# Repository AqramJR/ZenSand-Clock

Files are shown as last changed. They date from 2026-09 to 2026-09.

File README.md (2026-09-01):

# ⏳ ZenSand Clock: The Smart Kinetic Sand Art

A premium, 3D-printed Smart Kinetic Sand Art Clock powered by ESP32. This project combines the mesmerizing, continuous motion of a kinetic sand wiper with a feature-rich, 100% non-blocking software architecture. 

It serves not only as an aesthetically pleasing desk clock but also as a fully functional Smart Home IoT device featuring a local Web Dashboard, live weather synchronization, Pomodoro focus mode, and smooth embedded animations.

## ✨ Key Features

* **100% Non-Blocking Architecture:** Built entirely on `millis()` state machines. The 28BYJ-48 stepper motor runs flawlessly using `AccelStepper::runSpeed()` without a single `delay()`, ensuring the sand wiper never stutters, even during Wi-Fi connection or HTTP parsing.
* **Local Web Dashboard:** A built-in, mobile-friendly HTML/JS web server. Adjust motor RPM, toggle direction, change clock faces, tweak OLED brightness, or send scrolling messages to the screen instantly from your phone.
* **Live Weather & NTP Sync:** Connects to Wi-Fi on-demand (or keeps it alive) to sync exact time via NTP and fetches live weather data (temperature & conditions) from the Open-Meteo API (No API key required!).
* **Pomodoro Zen Mode:** A dedicated focus timer (25m work / 5m break). The sand moves agonizingly slow while you focus, then speeds up to "wipe the slate clean" during your break.
* **Smart Auto-Wipe:** Configurable daily schedules (e.g., 03:00 and 15:00) where the motor ramps up to maximum RPM for a deep sand-cleaning cycle.
* **Easter Egg Mini-Game:** Tap the capacitive sensor exactly 5 times rapidly to launch a hidden "Dino Jump" side-scroller game on the OLED!
* **Advanced U8g2 Animations:** Features multiple parallax and mathematically driven clock faces (e.g., Cyberpunk Neon Skyline, Star Voyage) running purely on calculated geometry.

## 🛠️ Hardware Requirements

* **Microcontroller:** ESP32 (NodeMCU-32S / WROOM-32)
* **Display:** 1.3" OLED SH1106 (I2C)
* **Touch Sensor:** TTP223 Capacitive Touch Module
* **Motor & Driver:** 28BYJ-48 Stepper Motor + ULN2003 Driver Board
* **RTC Module:** DS1307 (I2C) + CR2032 Coin Cell Battery
* **Sand Medium:** Kinetic sand (or ultra-fine baking soda)
* **Chassis:** 3D Printed housing (Sand tray and motor mount).

## 💻 Software Dependencies

Ensure you have the following libraries installed in your Arduino IDE:
* `U8g2` by olikraus
* `AccelStepper` by Mike McCauley
* `RTClib` by Adafruit
* `ArduinoJson` by Benoit Blanchon (v6.x)
* Built-in ESP32 Libraries: `WiFi.h`, `Preferences.h`, `WebServer.h`, `HTTPClient.h`

## 🔌 Wiring Guide

| Component | Pin | ESP32 Pin |
| :--- | :--- | :--- |
| **OLED & RTC** | SDA | `GPIO 21` |
| **OLED & RTC** | SCL | `GPIO 22` |
| **TTP223 Touch** | SIG | `GPIO 4` |
| **ULN2003 IN1** | IN1 | `GPIO 13` |
| **ULN2003 IN2** | IN2 | `GPIO 14` |
| **ULN2003 IN3** | IN3 | `GPIO 12` |
| **ULN2003 IN4** | IN4 | `GPIO 27` |

*(Note: The `AccelStepper` constructor in the code correctly handles the IN1-IN3-IN2-IN4 half-step sequence required for the 28BYJ-48 motor).*

## ⚙️ Software Setup

1. Install the latest **Arduino IDE**.
2. Add the ESP32 board package to your Boards Manager.
3. Install the following libraries via the Library Manager:
   * `U8g2` by olikraus
   * `AccelStepper` by Mike McCauley
   * `RTClib` by Adafruit
   * `ArduinoJson` by Benoit Blanchon
4. Open the `.ino` file and update your Wi-Fi credentials:
   ```cpp
   const char* WIFI_SSID     = "YOUR_SSID";
   const char* WIFI_PASSWORD = "YOUR_PASSWORD";
   ```
5. Adjust your Timezone offsets if necessary:
   ```cpp
   const long  GMT_OFFSET_SEC   = 7200;   // Example: UTC+2 (Egypt)
   const int   DST_OFFSET_SEC   = 0;      // Example: Daylight Savings Time
   ```
6. Compile and upload to your ESP32.

---

## 🚀 What's Next? (Future Upgrades)

This project is continuously evolving. Here is the roadmap for upcoming enhancements:

### 🔩 Hardware Upgrades
* **Battery Independence:** Integrate an 18650 Li-ion battery, TP4056 charging module, and MT3608 boost converter for a truly wire-free centerpiece.
* **Neopixel Edge-Lighting:** Add an addressable WS2812B LED strip beneath the sand basin. The ESP32 can sync the sand color with the current weather, time of day, or Pomodoro status.
* **Acoustic Ambience:** Incorporate a DFPlayer Mini and a 3W speaker to play Zen/Lo-Fi music, rain sounds, or an elegant hourly chime.
* **Glass Dome Enclosure:** Fit a custom acrylic or tempered glass dome to protect the sand from dust and humidity.

### 💾 Software/Firmware Upgrades
* **OTA (Over-The-Air) Updates:** Flash new firmware wirelessly through the web dashboard without dismantling the clock.
* **Kinetic Spirograph Patterns:** Upgrade the motor control math to draw complex geometric Mandala and Lissajous curves instead of simple circles.
* **Moon Phase Clock Face:** Calculate and render accurate lunar phases on the OLED alongside the date and time.
* **Kinetic Alarm Clock:** An alarm mode that vibrates the stepper motor rapidly and flashes the OLED to wake you up without needing a buzzer.

## 📝 License
This project is open-source. Feel free to fork, modify, and build your own ZenSand Clock!

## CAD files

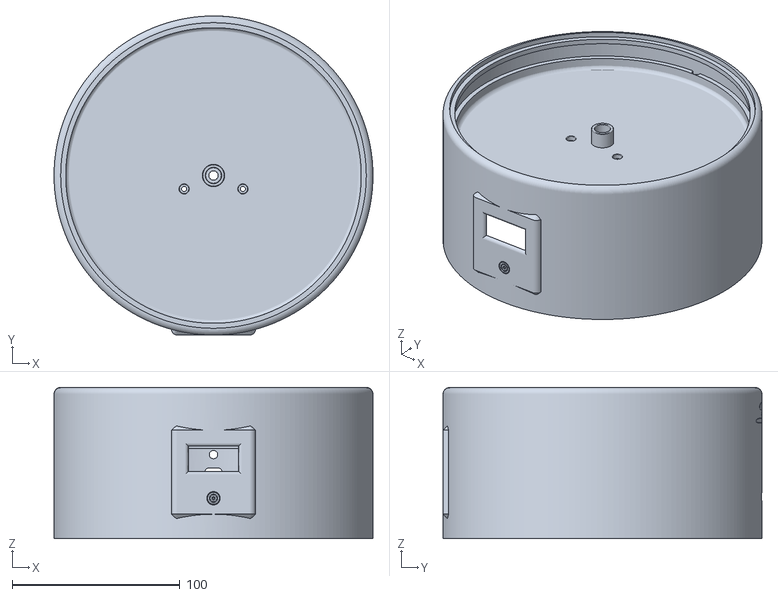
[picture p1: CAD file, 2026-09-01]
3D print/Main_Body_V2.stl
190.0 x 190.0 x 90.0

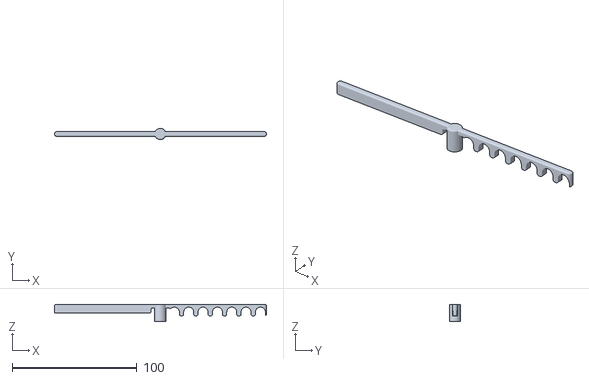
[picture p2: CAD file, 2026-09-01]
3D print/Sand_Wiper.stl
170.0 x 9.00 x 14.0

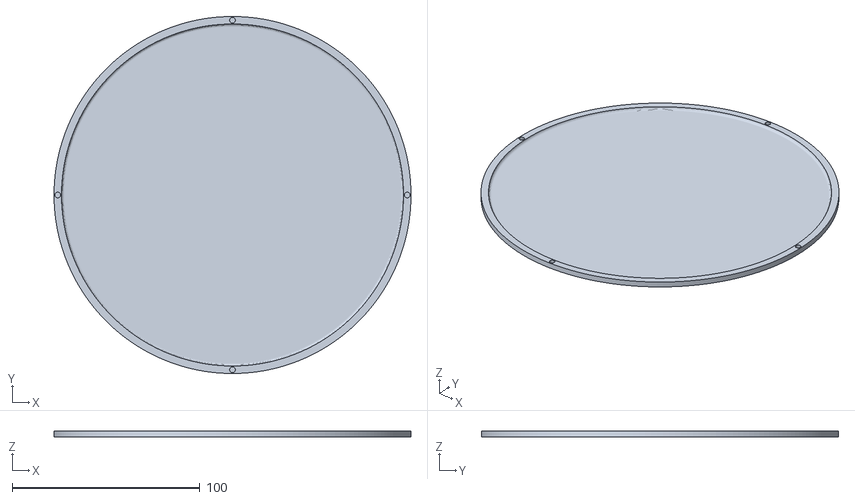
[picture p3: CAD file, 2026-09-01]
3D print/Bottom_Cover.stl
190.0 x 190.0 x 3.00

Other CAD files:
3D print/SmartSandClock.f3z

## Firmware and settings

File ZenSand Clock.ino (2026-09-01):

/*
 * ============================================================================
 *  SMART KINETIC SAND ART CLOCK — ESP32  (PREMIUM SMART-HOME EDITION)
 * ============================================================================
 *  Hardware:
 *    - ESP32 (NodeMCU-32S)
 *    - 1.3" OLED SH1106, I2C            -> U8g2 (full buffer, hardware I2C)
 *    - TTP223 capacitive touch          -> GPIO 4, Active HIGH
 *    - 28BYJ-48 + ULN2003               -> GPIO 13, 14, 12, 27, AccelStepper
 *    - DS1307 RTC, I2C                  -> RTClib (Adafruit)
 *
 *  Libraries required (Library Manager):
 *    - U8g2 by olikraus
 *    - AccelStepper by Mike McCauley
 *    - RTClib by Adafruit
 *    - ArduinoJson by Benoit Blanchon (v6.x)
 *    - (built into ESP32 core) Preferences.h, WiFi.h, time.h, WebServer.h,
 *      HTTPClient.h, Update.h
 *
 *  ============================================================================
 *  WHAT'S NEW IN THIS EDITION (6 features layered onto the original base)
 *  ============================================================================
 *   1. Local Web Dashboard   - WebServer.h, fully non-blocking (server.handleClient()
 *                              is called once per loop(), same as stepper.runSpeed()).
 *                              Mobile-friendly single-page HTML/CSS/JS control panel.
 *   2. Web Message Billboard - text box on the dashboard -> SystemState::BILLBOARD,
 *                              a millis()-driven horizontal scroll for ~5s.
 *   3. Live Weather Sync     - piggybacks on the existing WiFi/NTP state machine;
 *                              one extra (still non-blocking-to-the-motor) HTTPClient
 *                              call, parsed with ArduinoJson. New ClockFace::WEATHER.
 *   4. Pomodoro Zen Mode     - SystemState::POMODORO, 25-min work (RPM_MIN) / 5-min
 *                              break (RPM_MAX) cycle with a big countdown.
 *   5. Smart 12h Auto-Wipe   - fires automatically at 03:00 and 15:00 for a 2-minute
 *                              full-speed sweep, independent of the manual per-hour
 *                              auto-wipe setting already in Motor Settings.
 *   6. Easter-Egg Mini-Game  - 5 rapid taps inside the tap window launches a simple
 *                              non-blocking "Dino Jump" game; short tap = jump,
 *                              long-press or a loss exits back to the clock.
 *
 *  ============================================================================
 *  THIS REVISION ADDS
 *  ============================================================================
 *   7. OTA Firmware Update   - Update.h + a "/update" POST endpoint reachable
 *                              from the web dashboard. Standard synchronous
 *                              WebServer OTA pattern. NOTE: because WebServer
 *                              reads the whole multipart upload inside a single
 *                              server.handleClient() call, the stepper WILL
 *                              pause for the (short) duration of the upload +
 *                              flash write - this is an inherent limitation of
 *                              using the synchronous WebServer library for OTA,
 *                              not an oversight. yield() is called on every
 *                              received chunk so the watchdog never trips.
 *   8. Moon Phase Clock Face - ClockFace::MOON_PHASE. Phase is computed with a
 *                              lightweight Conway synodic-month approximation
 *                              (cheap integer/float math, no blocking calls,
 *                              no external library) and rendered as a real
 *                              illuminated disc using a per-scanline terminator
 *                              calculation (sqrt + cos, drawn with u8g2.drawHLine).
 *   9. WiFi Sync IP Display  - drawWifiSyncScreen() now prints WiFi.localIP()
 *                              on the OLED once sync succeeds, so the user can
 *                              find the dashboard without a Serial Monitor.
 *  10. "Always On" Label     - SLEEP_OPTIONS[0] (=0 minutes/never sleep) is now
 *                              rendered as "Always On" in both the OLED Display
 *                              Settings menu and the web dashboard status line.
 *
 *  ============================================================================
 *  THIS REVISION ALSO ADDS
 *  ============================================================================
 *  11. Zen Breathing Face    - ClockFace::ZEN_BREATHING. A sine-driven circle
 *                              that expands/contracts on an 8s inhale/exhale
 *                              cycle. Creative touch: updateZenBreathingMotor()
 *                              (called once per loop() pass, just like the
 *                              stepper itself) gently modulates motorRPM
 *                              +-30% around whatever speed the user had set,
 *                              faster at the inhale peak, slower on the
 *                              exhale - turning the wiper into a tactile
 *                              breathing pacer. The user's original RPM/dir/
 *                              run-state is saved on entry and restored
 *                              exactly on exit, so nothing else is disturbed.
 *  12. Generative Sand Art   - ClockFace::GENERATIVE_ART. A lightweight
 *                              falling-sand cellular automaton (64x32 logical
 *                              grid, 2px cells) that trickles grains downward
 *                              and piles them up, redrawn once per throttled
 *                              display refresh (same 200ms cadence as every
 *                              other face, so it never competes with the
 *                              stepper for CPU time). The digital time is
 *                              drawn on top inside a solid-filled panel so
 *                              it always stays crisp and readable.
 *  13. IP Wrap Fix           - drawWifiSyncScreen() now renders the synced
 *                              dashboard IP with a compact "IP: " prefix on
 *                              the small 5x7 font and centers/measures it
 *                              with getStrWidth() before drawing, so a full
 *                              IPv4 address ("IP: 255.255.255.255") always
 *                              fits inside the 128px screen width instead of
 *                              being clipped off the right edge.
 *
 *  Design notes (unchanged core philosophy):
 *    - ZERO calls to delay() anywhere in the steady-state loop() path. Every
 *      timed behaviour is driven off millis() state machines so the stepper
 *      and the touch polling are never blocked for more than a few
 *      milliseconds (the unavoidable I2C transfer time when we push a frame
 *      to the OLED). The ONE exception in the whole sketch is a short,
 *      clearly-commented delay() in handleUpdateResult(), used only after a
 *      successful OTA flash, immediately before ESP.restart() - at that point
 *      the MCU is about to fully reboot and re-initialise everything, so it
 *      has no bearing on the "smooth stepper during normal operation"
 *      guarantee.
 *    - AccelStepper::runSpeed() is called on every single pass through
 *      loop() so the sand wiper keeps perfectly smooth, constant-velocity
 *      motion regardless of what the UI/touch/web/HTTP logic is doing.
 *    - WebServer::handleClient() and the weather HTTPClient call are the two
 *      operations most likely to introduce latency; handleClient() is cheap
 *      and non-blocking by design, and the weather HTTP GET is only ever
 *      issued once per NTP sync (a rare, user-initiated or hourly event),
 *      immediately followed by stepper.runSpeed() calls before and after so
 *      any momentary stall is bounded and imperceptible on a slow sand wiper.
 *      The OTA upload endpoint is the sole exception, documented above.
 * ============================================================================
 */

#include <Arduino.h>
#include <Wire.h>
#include <U8g2lib.h>
#include <AccelStepper.h>
#include <RTClib.h>
#include <Preferences.h>   // NVS persistence
#include <WiFi.h>          // NTP sync + Web Dashboard + Weather
#include <time.h>          // configTime()/time()
#include <WebServer.h>     // Feature 1: local web dashboard
#include <HTTPClient.h>     // Feature 3: OpenWeatherMap / Open-Meteo
#include <ArduinoJson.h>    // Feature 3: JSON parsing
#include <Update.h>         // Feature 7: OTA firmware updates

// ============================================================================
//  PIN DEFINITIONS
// ============================================================================
static const uint8_t PIN_TOUCH   = 4;                 // TTP223, active HIGH

static const uint8_t PIN_STEP_IN1 = 13;
static const uint8_t PIN_STEP_IN2 = 14;
static const uint8_t PIN_STEP_IN3 = 12;
static const uint8_t PIN_STEP_IN4 = 27;

// ============================================================================
//  DISPLAY  (SH1106, full frame buffer, hardware I2C)
// ============================================================================
U8G2_SH1106_128X64_NONAME_F_HW_I2C u8g2(U8G2_R0, /* reset=*/ U8X8_PIN_NONE);

// ============================================================================
//  RTC
// ============================================================================
RTC_DS1307 rtc;
bool rtcAvailable = false;

// ============================================================================
//  STEPPER  (28BYJ-48 / ULN2003, half-step mode -> 2048 steps/rev)
// ============================================================================
AccelStepper stepper(AccelStepper::HALF4WIRE,
                      PIN_STEP_IN1, PIN_STEP_IN3, PIN_STEP_IN2, PIN_STEP_IN4);

static const float STEPS_PER_REV = 2048.0f;

float    motorRPM      = 1.0f;   // default: 1 RPM
int8_t   motorDirection = 1;     // +1 = clockwise, -1 = counter-clockwise
bool     motorRunning   = true;

static const float RPM_STEP = 5.0f;
static const float RPM_MIN  = 1.0f;
static const float RPM_MAX  = 15.0f;

// ============================================================================
//  PERSISTENT SETTINGS (NVS via Preferences)
// ============================================================================
Preferences prefs;
static const char* NVS_NAMESPACE = "sandclock";

// ============================================================================
//  STATE MACHINE & MENUS
// ============================================================================
enum class SystemState : uint8_t {
  BOOT, MAIN_SCREEN, SETTINGS_MENU, MOTOR_MENU, DISPLAY_MENU, TIME_SET_MENU,
  ANIMATION, WIFI_SYNC, WIPE_ACTIVE,
  POMODORO,     // Feature 4
  BILLBOARD,    // Feature 2
  GAME          // Feature 6
};

enum class ClockFace : uint8_t {
  DIGITAL_HUGE, ANALOG_CLOCK, DATE_TIME, BINARY_CLOCK, RPM_VIEW,
  CARTOON_MODE, CARTOON_MOVIE_2,
  WEATHER,        // Feature 3
  MOON_PHASE,     // Feature 8
  ZEN_BREATHING,  // Feature 11 (this revision)
  GENERATIVE_ART, // Feature 12 (this revision)
  FACE_COUNT
};

SystemState currentState  = SystemState::BOOT;
SystemState stateBeforeAnimation = SystemState::MAIN_SCREEN;
ClockFace   currentFace   = ClockFace::DIGITAL_HUGE;

uint8_t settingsMenuIndex = 0;
uint8_t motorMenuIndex    = 0;
uint8_t displayMenuIndex  = 0;
uint8_t timeSetStep = 0; // 0 = hours, 1 = minutes
int8_t tempHour = 0;
int8_t tempMinute = 0;

// Settings menu now offers Pomodoro entry too.
const char* SETTINGS_ITEMS[] = { "1.Motor Settings", "2.Display Settings", "3.Set Time", "4.Sync WiFi Time", "5.Pomodoro Mode", "< Back" };
const uint8_t SETTINGS_ITEM_COUNT = 6;
static const uint8_t SETTINGS_IDX_MOTOR    = 0;
static const uint8_t SETTINGS_IDX_DISPLAY  = 1;
static const uint8_t SETTINGS_IDX_SET_TIME = 2;
static const uint8_t SETTINGS_IDX_WIFI     = 3;
static const uint8_t SETTINGS_IDX_POMODORO = 4;
static const uint8_t SETTINGS_IDX_BACK     = 5;

const char* MOTOR_ITEMS[] = { "Speed Up", "Speed Down", "Max RPM", "Toggle Direction", "Stop/Start Motor", "Auto-Wipe Hour", "< Back" };
const uint8_t MOTOR_ITEM_COUNT = 7;
static const uint8_t MOTOR_IDX_SPEED_UP   = 0;
static const uint8_t MOTOR_IDX_SPEED_DOWN = 1;
static const uint8_t MOTOR_IDX_MAX_RPM    = 2;
static const uint8_t MOTOR_IDX_TOGGLE_DIR = 3;
static const uint8_t MOTOR_IDX_TOGGLE_RUN = 4;
static const uint8_t MOTOR_IDX_AUTO_WIPE  = 5;
static const uint8_t MOTOR_IDX_BACK       = 6;

const char* DISPLAY_ITEMS[] = { "1.Brightness", "2.Auto-Sleep", "3.Time Format", "< Back" };
const uint8_t DISPLAY_ITEM_COUNT = 4;

const uint8_t SLEEP_OPTIONS[] = { 0, 1, 3, 5, 10 };
const uint8_t SLEEP_OPTION_COUNT = 5;
uint8_t sleepOptionIndex = 0;

uint8_t brightnessIndex = 2;
const uint8_t BRIGHTNESS_LEVELS[] = {10, 100, 255};
const char* BRIGHTNESS_NAMES[] = {"Low", "Med", "High"};

uint8_t currentAnimType = 0;

bool use12HourFormat = true;

// ---- Feature: Manual scheduled daily auto-wipe (Motor Settings entry) ----
static const uint8_t WIPE_HOUR_OFF = 255;
uint8_t wipeHourSetting = WIPE_HOUR_OFF;
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
void loop() {
  // 1) Motor: must run every single pass for smooth constant-velocity motion.
  updateMotor();

  // 2) Touch input: fully non-blocking, millis()-based.
  pollTouch();

  // 3) Boot screen timeout.
  if (currentState == SystemState::BOOT &&
      millis() - bootStartTime >= BOOT_DURATION_MS) {
    currentState = SystemState::MAIN_SCREEN;
    triggerGreeting();
  }

  // 4) Animation overlay timeout.
  if (currentState == SystemState::ANIMATION &&
      millis() - animStartTime >= ANIM_DURATION_MS) {
    currentState = stateBeforeAnimation;
  }

  // 4.5) WiFi/NTP (+ weather) sync state machine.
  if (currentState == SystemState::WIFI_SYNC) {
    updateWifiSync();
  }

  // 4.6) Auto-wipe (manual per-hour OR smart 12h) full-speed sweep.
  if (currentState == SystemState::WIPE_ACTIVE) {
    updateWipe();
  }

  // 4.7) Pomodoro Zen Mode.
  if (currentState == SystemState::POMODORO) {
    updatePomodoro();
  }

  // 4.8) Billboard scroll timeout / auto-return.
  if (currentState == SystemState::BILLBOARD) {
    if (millis() - billboardStartTime >= BILLBOARD_DURATION_MS) {
      currentState = stateBeforeBillboard;
    }
  }

  // 4.9) Easter-egg mini-game physics tick.
  if (currentState == SystemState::GAME) {
    updateGame();
  }

  // 4.95) Feature 11: keep the motor speed synced to the breathing rhythm
  //       whenever the Zen Breathing face is showing on the main screen.
  //       Cheap (a handful of float ops), so it runs every loop() pass just
  //       like updateMotor() - it also transparently no-ops (and restores
  //       the user's normal RPM) the instant the face/state changes away.
  updateZenBreathingMotor();

  // 5) Shared hourly-granularity checks (contrast + both wipe schedules).
  if (millis() - lastContrastCheck >= CONTRAST_CHECK_INTERVAL_MS) {
    lastContrastCheck = millis();
    periodicTimeBasedChecks();
  }

  // 5.1) Auto-sleep bookkeeping.
  updateSleepTimer();

  // 5.2) Auto-exit settings menus after inactivity (also commits to NVS).
  if (currentState == SystemState::SETTINGS_MENU ||
      currentState == SystemState::MOTOR_MENU ||
      currentState == SystemState::DISPLAY_MENU ||
      currentState == SystemState::TIME_SET_MENU) {
    if (millis() - lastInteractionTime >= MENU_TIMEOUT_MS) {
      exitSettingsMenus();
    }
  }

  // 6) Feature 1: service the web dashboard (incl. Feature 7 OTA endpoint).
  //    WebServer::handleClient() only does real work when a client has an
  //    open/pending request, so on a typical pass through loop() this is a
  //    cheap socket poll - it never introduces a meaningful stall for the
  //    stepper. The one exception is an in-progress OTA upload, which is a
  //    rare, user-initiated event (see the notes at the top of the file and
  //    on handleUpdateUpload() below).
  if (webServerStarted) {
    server.handleClient();
  } else if (KEEP_WIFI_ALWAYS_ON && WiFi.status() == WL_CONNECTED) {
    startWebServer();
  }

  // 7) Throttled display refresh.
  unsigned long now = millis();
  unsigned long interval = (currentState == SystemState::ANIMATION) ? ANIM_FRAME_MS
                                                                     : DISPLAY_INTERVAL_MS;
  if (!displayAsleep && (now - lastDisplayUpdate >= interval)) {
    lastDisplayUpdate = now;
    renderDisplay();
  }

  // 8) Run the motor once more right after the (short) I2C/web transfer
  //    above, to minimise any timing skew.
  updateMotor();
}

// ============================================================================
//  SETTINGS EXIT HELPER
// ============================================================================
void exitSettingsMenus() {
  saveSettings();
  currentState = SystemState::MAIN_SCREEN;
}

// ============================================================================
//  MOTOR CONTROL
// ============================================================================
void updateMotor() {
  stepper.runSpeed();
}

void applyMotorSpeed() {
  float stepsPerSecond = (motorRPM * STEPS_PER_REV) / 60.0f;
  float signedSpeed = motorRunning ? (motorDirection * stepsPerSecond) : 0.0f;
  stepper.setSpeed(signedSpeed);
}

// Thin forwarders so Pomodoro block (declared earlier in the file, ahead of
// applyMotorSpeed()/lastInteractionTime's normal usage sites) can reach them
// without a full file reorder.
void applyMotorSpeedFwd() { applyMotorSpeed(); }
void lastInteractionTimeFwd() { lastInteractionTime = millis(); }

void increaseSpeed() {
  motorRPM = min(RPM_MAX, motorRPM + RPM_STEP);
  applyMotorSpeed();
}

void decreaseSpeed() {
  motorRPM = max(RPM_MIN, motorRPM - RPM_STEP);
  applyMotorSpeed();
}

void setMaxRPM() {
  motorRPM = RPM_MAX;
  applyMotorSpeed();
}

void toggleDirection() {
  motorDirection = -motorDirection;
  applyMotorSpeed();
}

void toggleMotorRunning() {
  motorRunning = !motorRunning;
  applyMotorSpeed();
}

// ============================================================================
//  TOUCH POLLING — time-window algorithm
// ============================================================================
void pollTouch() {
  bool reading = digitalRead(PIN_TOUCH);

  if (reading != lastRawReading) {
    lastDebounceTime = millis();
  }
  lastRawReading = reading;

  if (millis() - lastDebounceTime > DEBOUNCE_MS) {
    if (reading != stableState) {
      stableState = reading;
      if (stableState == HIGH) {
        onTouchPress();
      } else {
        onTouchRelease();
      }
    }
  }

  if (isPressed && !longPressFired && !suppressThisPress) {
    if (millis() - pressStartTime >= LONG_PRESS_MS) {
      longPressFired = true;
      onLongPress();
    }
  }

  if (tapWindowOpen && (millis() - tapWindowStart >= TAP_WINDOW_MS)) {
    tapWindowOpen = false;
    resolveTapSequence(tapCount);
    tapCount = 0;
  }
}

void onTouchPress() {
  lastInteractionTime = millis();

  if (displayAsleep) {
    wakeDisplay();
    suppressThisPress = true;
    isPressed = true;
    pressStartTime = millis();
    longPressFired = false;
    return;
  }

  isPressed = true;
  pressStartTime = millis();
  longPressFired = false;

  // In-game: a press is treated as an immediate jump input rather than
  // waiting for the tap-window to resolve, so the game feels responsive.
  if (currentState == SystemState::GAME) {
    if (gameOver) {
      // tap on the game-over screen retries
      startGame();
    } else {
      gameJump();
    }
  }
}

void onTouchRelease() {
  isPressed = false;

  if (suppressThisPress) {
    suppressThisPress = false;
    return;
  }

  if (longPressFired) {
    longPressFired = false;
    return;
  }

  tapCount++;
  tapWindowOpen = true;
  tapWindowStart = millis();
}

void resolveTapSequence(uint8_t count) {
  // Feature 6: exactly 5 rapid taps launches the Easter-egg game from any
  // normal clock/menu context (but not from inside another modal like
  // billboard/pomodoro/wipe, so those aren't accidentally interrupted).
  if (count == GAME_TRIGGER_TAPS &&
      (currentState == SystemState::MAIN_SCREEN ||
       currentState == SystemState::SETTINGS_MENU ||
       currentState == SystemState::MOTOR_MENU ||
       currentState == SystemState::DISPLAY_MENU)) {
    startGame();
    return;
  }

  switch (currentState) {
    case SystemState::MAIN_SCREEN:
      if (count == 2) {
        cycleClockFace();
      } else if (count == 3) {
        startAnimation();
      }
      break;

    case SystemState::ANIMATION:
      if (count == 2) {
        currentState = stateBeforeAnimation;
      }
      break;

    case SystemState::SETTINGS_MENU:
      settingsMenuIndex = (settingsMenuIndex + 1) % SETTINGS_ITEM_COUNT;
      break;

    case SystemState::MOTOR_MENU:
      motorMenuIndex = (motorMenuIndex + 1) % MOTOR_ITEM_COUNT;
      break;

    case SystemState::DISPLAY_MENU:
      displayMenuIndex = (displayMenuIndex + 1) % DISPLAY_ITEM_COUNT;
      break;

    case SystemState::TIME_SET_MENU:
      if (timeSetStep == 0) {
        tempHour = (tempHour + 1) % 24;
      } else {
        tempMinute = (tempMinute + 1) % 60;
      }
      break;

    case SystemState::GAME:
      // handled immediately in onTouchPress(); nothing further needed here.
      break;

    case SystemState::BILLBOARD:
      // any tap cancels the billboard early.
      currentState = stateBeforeBillboard;
      break;

    default:
      break;
  }
}
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
